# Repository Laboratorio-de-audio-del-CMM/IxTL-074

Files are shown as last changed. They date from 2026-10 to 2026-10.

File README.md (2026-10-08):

# IxTL-074
IxTL-074

El IxTL-074 es un sintetizador DIY de frecuencia modulada (FM) desarrollado en el Laboratorio de Experimentación Sonora del Centro Multimedia entre agosto y octubre del 2026.

Su nombre proviene de un juego de palabras derivado del nombre de la fibra vegetal extraida de algunas especies de maguey (Ixtle[^1]) y uno de los componentes del sintetizador (el amplificador operacional TL-074). Busca trazar un paralelismo entre el tejido material de fibras vegetales y el sonido derivado de las interconecciones entre operadores de la síntesis FM.

## Funcionamiento
El IxTL-074 se compone de cuatro osciladores de onda cuadrada, cada uno con un rango de oscilación dedicado:

* **Oscilador 1:** 1.7 - 140 Hz aproximadamente
* **Oscilador 2:** 6.5 - 463 Hz aproximadamente
* **Oscilador 3:** 137 - 2266 Hz aproximadamente
* **Oscilador 4:** 147 - 5848 Hz aproximadamente

La frecuencia y amplitud de cada oscilador son determinadas por controles dedicados. La frecuencia puede ser variada mediante una señal moduladora [^2].

Cada oscilador cuenta con:
* **Tres salidas:**
    
    Correspondientes a la frecuencia y a la amplitud establecida con los controles dedicados. Cada salida puede funcionar como:
    * señal de audio, al conectarse a la mezcladora integrada
    * señal moduladora, al conectarse a las entradas de otro oscilador, o a su propia entrada

* **Tres entradas**

    Receptoras de señales moduladoras que deriavarán en variaciones de frecuencia de las señales portadoras.

Cada oscilador tiene la capacidad de operar como señal portadora y moduladora simultaneamente.

Las conxiones entre salidas, entradas y mezcladora se establecen utilizando cables puente con puntas macho (también conocidos como "jumpers" o cables DuPont).

El sintetizador funciona con una fuente de alimentación de 9v con punta positiva.

La salida de audio integrada duplica una señal monofónica de audio (doble mono).

## Lista de materiales

La lista completa de materiales necesarios para la construcción del IxTL-074 es:

* **Circuitos integrados**
    * Inversor Schmitt trigger 40106 x1
    * Amplificador operacional TL-074 x1

* **Potenciómetros**
    * 10k x1
    * 50k x6
    * 100k x2

* **Capacitores electrolíticos**
    * 0.22μF x1
    * 1μF x2
    * 4.7μF x1
    * 10μF x1

* **Capacitores cerámicos**
    * 100nF x5

* **Resistencias**
    * 470 x3
    * 1k x6
    * 10k x4
    * 100k x2

* **Otros componentes**
    * Transistor 2N394 x1
    * LED de 5mm x1
    * Header hembra de 2x2 x1
    * Headers hembra de 2x3 x4
    * Switch SPDT x1
    * Conector jack hembra de 3.5mm SJ1-3515 x1
    * Barril jack de 5.5mm x 2.1mm
    * Fuente de alimentación de 9v con salida jack de punta positiva de 5.5mm x 2.1mm (se recomienda una pila de 9v con broche)

Los headers pueden sustituirse con una tira larga (que usualmente es más fácil de conseguir) y ser recortados posteriormente.

El conector de jack de 3.5mm también puede ser sustituido por un conector más fácil de conseguir o que se adapte mejor a las necesidades de quien lo construya.

## Apoyo a la documentación 
El repositorio posee una carpeta y un archivo adicional de apoyo a la documentación:

1. Carpeta _**Esquemático**_:

    Contiene el diagrama esquemático de la versión 1.0.0 del sintetizador en versión pdf y en archivo editable de KiCad .kicad_sch

2. Archivo _**Diseño.md**_

    Contiene una descripción general del diseño electrónico del sintetizador para quien desee profundizar en su funcionamiento.

## Licencia
En concordancia a los valores del conocimiento abierto, que promueven un acceso justo y equitativo a la información, la investigación y la producción de aprendizaje, el presente hadware se distribuye bajo la licencia **CERN Open Hardware Licence Version 2 - Strongly Reciprocal (CERN-OHL-S-2.0)**, con las siguientes implicaciones:

* **Libertad de uso y fabricación:** Tienes libertad para copiar, modificar y distribuir los archivos de diseño, así como para fabricar, ensamblar y vender productos físicos basados en ellos.
* **Reciprocidad fuerte (Copyleft fuerte):** Si modificas los archivos de diseño o distribuyes productos físicos creados a partir de ellos, estás obligado a liberar todo el diseño derivado bajo esta misma licencia (CERN-OHL-S v2).
* **Disponibilidad del código fuente:** Debes facilitar a los receptores el acceso al código fuente completo (archivos de diseño, esquemáticos, CAD) o indicar claramente la ubicación digital donde puedan descargarlo.
* **Atribución y registro de cambios:** Es obligatorio conservar los avisos de derechos de autor originales y añadir una nota indicando la fecha y una breve descripción de las modificaciones que hayas realizado.
* **Licencia de patentes:** Incluye una concesión de patentes perpetua y sin regalías para fabricar y vender el hardware. Esta concesión se revoca automáticamente si alguien inicia un litigio de patentes contra el proyecto.
* **Sin garantía:** El diseño y los objetos creados se proporcionan "tal cual" (*as is*), sin garantías de funcionamiento o comercialización, y sin responsabilidad legal para los creadores originales.

Para leer el texto legal completo y detallado, consulta el archivo [LICENCE](LICENCE) en este repositorio.

## Créditos

* #### Investigación, desarrollo y diseño de tarjeta de circuito impreso:
    Francisco Ibrahim :shipit:, Colaborador del Laboratorio de Experimentación Sonora.
* #### Investigación, asesoramiento y supervisión del proyecto:
    Gonzalo T. Alonso, Jefe del Laboratorio de Experimentación Sonora.

### Agradecimientos
* **Centro Multimedia** del Centro Nacional de las Artes.
* **Juan Galindo**, Jefe del Laboratorio de Robótica y Sistemas Complejos.
* [**Proyecto KiCad**](https://www.kicad.org/) de software libre para la automatización del diseño electrónico.
* Productores cafetaleros de Veracruz y Chiapas.

## Documentación consultada
* Collins N. (2020). Handmade electronic music. New York: Routledge Taylor & Francis Group.
* Electro-Music. (s. f.). Simple 40106 oscillator with diode-based CV input [Archivo PDF]. https://electro-music.com/forum/phpbb-files/rmr_001__simple_40106_oscillator_with_diode_based_cv_input_905.pdf
* Evil Turtle Productions. (s. f.). Analog FM Drone/Kick Synth. https://www.evilturtle.nl/projects/fm-drone-synth
* Keim, R. (2020). Op-Amp Basics: Introduction to the Operational Amplifier. All About Circuits. https://www.allaboutcircuits.com/video-tutorials/op-amp-basics-introduction-to-the-operational-amplifier/
* Klein, M., & Erica Synths. (2021). mki x es.edu VCO manual [Archivo PDF]. Erica Synths.
* Lis A. (2022). 40106 dual oscillator. SFCS: Synthfox Custom Stuff. https://sfcs.neocities.org/module/SFP21/
* Williams, E. (2015). Logic noise: Sweet, sweet oscillator sounds. Hackaday. https://hackaday.com/2015/02/04/logic-noise-sweet-sweet-oscillator-sounds/

[^1]: Más información sobre el Ixtle y su uso en el Valle del Mezquital: https://tesiunamdocumentos.dgb.unam.mx/ptd2013/octubre/0702151/Index.html
[^2]: La modulación de frecuencia es un método de síntesis sonora. Consiste en variar (modular) la frecuencia de una señal (denominada portadora) con respecto a otra (denominada moduladora). El rango de la modulación de la frecuencia de la señal portadora será proporcional a la amplitud de la señal moduladora. La velocidad de la modulación de la frecuencia de la señal portadora será proporcional a la frecuencia de la señal moduladora.

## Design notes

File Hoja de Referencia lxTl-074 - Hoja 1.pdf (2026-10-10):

lxTl-074
Componente | Referencia | Qty | Valor
Capacitor cerámico | C2, C4, C6, C8, C10 | 5 | 100nF (104)
Capacitor electrolítico | C1 | 1 | 10µF
| C3 | 1 | 4.7¬µF
| C5 | 1 | 1¬µF
| C7 | 1 | 0.22¬µF
| C9 | 1 | 1uF
Conector header | J1, J2, J3, J4 | 4 | Pin Header 2x3 Female
| J5 | 1 | Pin Header Feamale 2x2
Conector de audio 3.5 | J6 | 1 | SJ1-3515
Conector DC | J7 | 1 | Barrel Jack
Led | LED1 | 1 | LED 5mm Azul
Transistor | Q1 | 1 | 2N3904
Potenciómetro | R2, R21 | 2 | POT 100k | B104
| R3, R6, R7, R11, R14, R15 | 6 | POT 50k | B503
| R10 | 1 | POT 10k | B103
Resistencia | R5, R9, R24 | 3 | 470 Ohm
| R1, R4, R8, R12, R13, R16 | 6 | 1k
| R17, R18, R19, R20 | 4 | 10k
| R22, R23 | 2 | 100k
Switch | SW1 | 1 | SPDT
Circuito Integrado | U1 | 1 | IC 40106
| U2 | 1 | TLC074

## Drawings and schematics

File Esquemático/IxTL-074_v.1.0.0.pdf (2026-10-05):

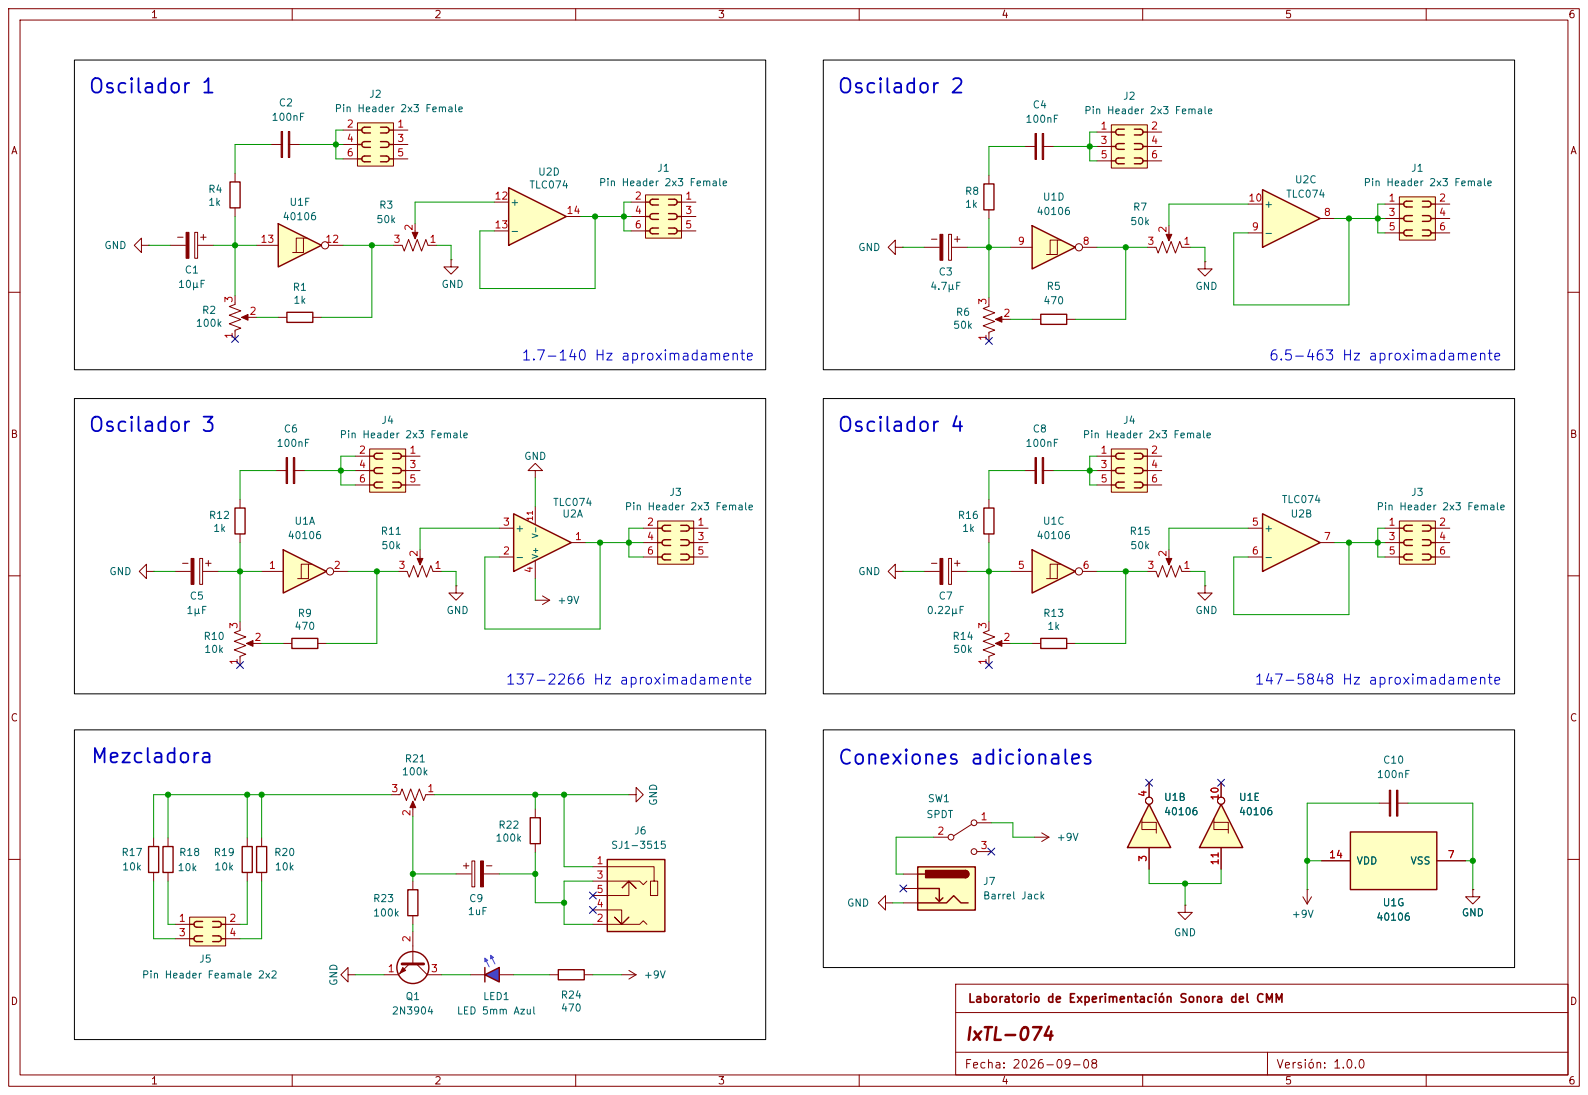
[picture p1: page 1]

J4 Pin Header 2x3 Female GND

J3 Pin Header 2x3 Female GND

Laboratorio de Experimentación Sonora del CMM
IxTL-074

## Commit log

2026-09-29 Creación de archivo .gitignore
2026-09-29 Actualización de licencia
    Actualización de licencia a GPL v3
2026-09-29 version preliminar de README.md
    Estructura general y descripción inicial. Commit para guardar y poder usar la rama en otra compu jeje
2026-09-29 Carpeta de archivos de fabricación gerber
    Se agrega la última versión de los archivos de fabricación de PCB gerber
    [IxTL-074_v.1.0.0-B_Cu.gbl, IxTL-074_v.1.0.0-B_Mask.gbs, IxTL-074_v.1.0.0-B_Silkscreen.gbo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]
2026-09-29 Se agrega carpeta con esquemático
    Se agrega la carpeta con el diagrama esquemático final del IxTL-074 v1.0.0
2026-09-29 Se agrega proyecto de KiCad
    Se agregan los archivos finales del proyecto de KiCad del IxTL-074 v1.0.0, incluyendo el ddiseño del esquemático y el proyecto de fabricación de la placa PCB
    [IxTL-074_v.1.0.0.kicad_pcb, IxTL-074_v.1.0.0.kicad_sch]
2026-09-30 Eliminación de archivos de fabricación
    Se eliminan gerbers y proyecto de KiCad
    [IxTL-074_v.1.0.0-B_Cu.gbl, IxTL-074_v.1.0.0-B_Mask.gbs, IxTL-074_v.1.0.0-B_Silkscreen.gbo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]
2026-09-30 Archivo preliminar de README.md
    Subida de cambios a la nube con actualizaciones importantes pero preliminares de README.md
2026-10-05 Actualización de esquemáticos
    Se agregan versiones corregidas del pdf y archivo de esquemático de kicad .kicad_shc
    [IxTL-074_v.1.0.0.kicad_sch]
2026-10-05 Actualización de README.md
    Versión preliminar para revisión
2026-10-07 Actualización de licenciamiento
    Actualización de licenciamiento a CERN-OHL-S-2.0
2026-10-07 Actualización de README.md
    Se corrigen imprecisiones referentes a l vocabulario de la síntesis FM, se plantea nuevo orden, se mejora el formato, se añaden referencias y se actualiza licencia
2026-10-07 Actualización de formato README.md
2026-10-10 Create Hoja de Referencia lxTl-074 - Hoja 1.pdf
2026-10-10 Update Hoja de Referencia lxTl-074 - Hoja 1.pdf
2026-10-14 Correciones de ortografía
2026-10-14 Actualización de .gitignore
2026-10-14 Imagen de esquemático de referencia
2026-10-14 Actualización de formato y secciones
2026-10-14 Actualización de documento de piezas
    Formato mejorado con anotaciones, colores y correcciones capacitores
2026-10-14 Se borra hoja preliminar de componentes
2026-10-17 Se agrega carpeta con archivos finales de fabricación
2026-10-17 Se agrega carpeta con archivos finales de proyecto KiCad
2026-10-17 Se agrega esquemático de alta resolución en formato pdf
2026-10-17 Se actualiza README con versión final de la documentación
    Larga vida al conocimiento abierto
2026-10-17 Se agrega archivo de diseño en formato markdown
2026-10-17 Se añaden imágenes de esquemáticos a diseño.md
    Siendo las 1:03 de la madrugada del sábado 17 de octubre de 2026, declaro terminada la versión 1.0.0 del IxTL-074.
    Gracias a Gonzalo y a el Centro Multimedia.
    -FI
2026-10-19 Links corregidos de README.md
